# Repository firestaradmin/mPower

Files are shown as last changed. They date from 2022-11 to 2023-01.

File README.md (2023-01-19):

---
title: mPower [USB-C功率计、快充诱骗器]
tags: 
- Embedded
- ESP32
- product
categories:
- [PROJECT, product]
cover: /img/covers/mPowerV2.png
banner_img: /img/page/mPowerV2.png
index_img: /img/page/mPowerV2.png
sticky: 2
date: 2022-12-14
updated: 2023-1-18
---

# mPower [USB-C功率计、快充诱骗器]

---

@firestaradmin 2022-12-14

**本项目已开源至Github：[点我传送](https://github.com/firestaradmin/mPower)**

---

[TOC]

## 1、简介：

**为什么叫 mPower 呢？**
首先mPower 可以看作是一个迷你的power 相关的东西吧，其次也是我喜欢的一款车--BMW mPower 4 （😄）

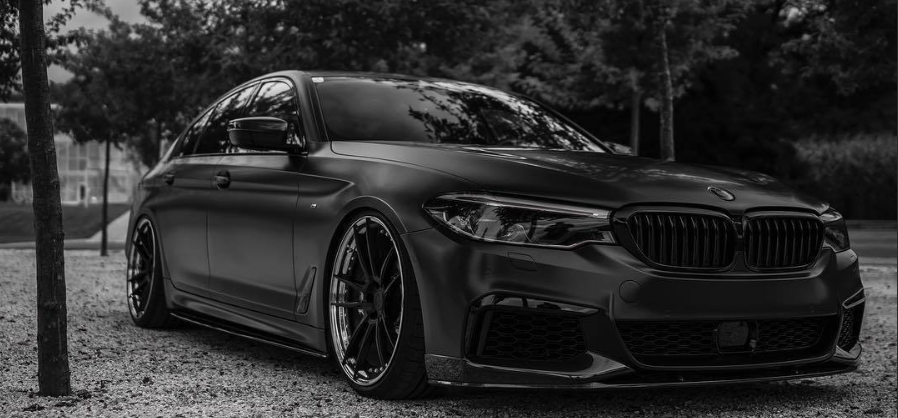
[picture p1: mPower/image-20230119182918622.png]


**功能介绍：**

首先是功率测量功能，顾名思义（USB-C功率计、快充诱骗器）它是一个USB-C 口的一个充电功率测量仪器，测量误差精确到`+-0.002 A/V`，但是DIY 作品并没有做偏差校准，所以并没有看上去那么精确，够用即可。

其次是PD快充协议诱骗功能，带有硬件开关一键诱骗，软件设置电压。如果快充适配器支持需要的电压就会输出该电压。

**硬件介绍：**

mPower 采用`ESP32-S2FH4`作为主控MCU，是一个单核 32 位 LX7 微处理器的 SoC，其内部集成4MB FLASH，支持WIFI 连接。

PCB 板载整合功能：USB串口电路、INA181电流检测芯片、一个SPI液晶屏幕IPX座子、一个输入端TYPE-C、一个输出TYPE-C、一个输出TYPE-A、一个输出正负极接线座子等

示意图：

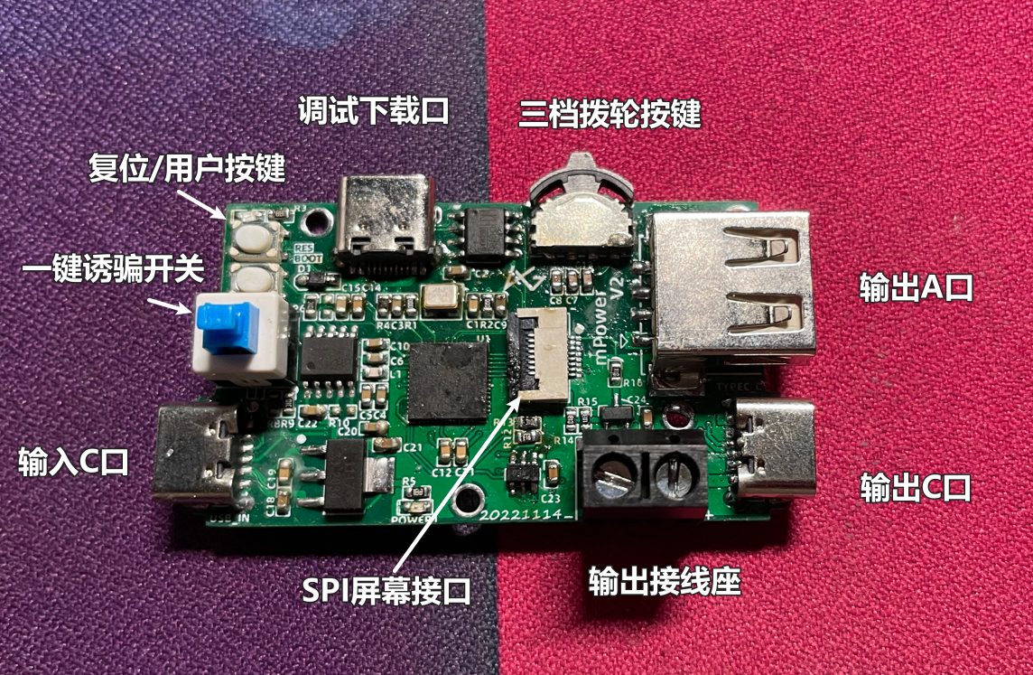
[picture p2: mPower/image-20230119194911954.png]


 背面靓照如下：

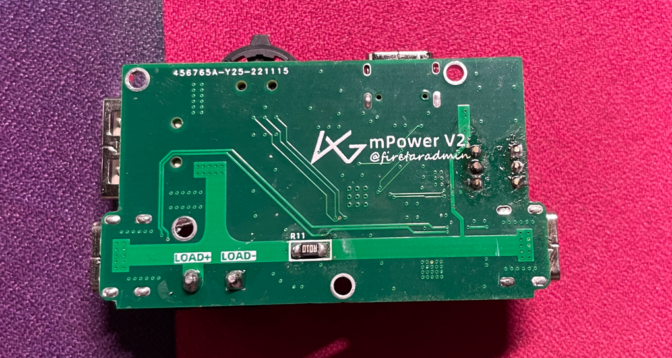
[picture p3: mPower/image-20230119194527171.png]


> mPower 本身是非常迷你的，尺寸只有 5CMx3CM

## 2、硬件电路部分

硬件电路部分，需要注意的是大电流走线宽度一定要够，其余的都很基础，参考器件的官方手册都可以解决，这里就不一一展示了，电路全部开源在GitHub。

诱骗采用的是 CH224K，支持PD协议的诱骗。

## 3、软件部分

软件部分，是基于FreeRTOS 的一个乐鑫提供SDK下开发的，整体思路就是ADC采集电压电流，然后计算转换为实际的电压电流显示在屏幕上。

电压采集直接ADC采集输出端或输入端的电压即可。

电流采集通过INA181芯片采集一个高精度的10毫欧采样电阻的电压来计算电流。

具体程序也开源在GitHub。

## 4、调试过程

因为我在制作这个东东的时候已经在准备辞职的事情了，所以上图二代的照片并没有记录其过程，这里只有一张第一代的mPower 的调试照片，还很糊，hhh。

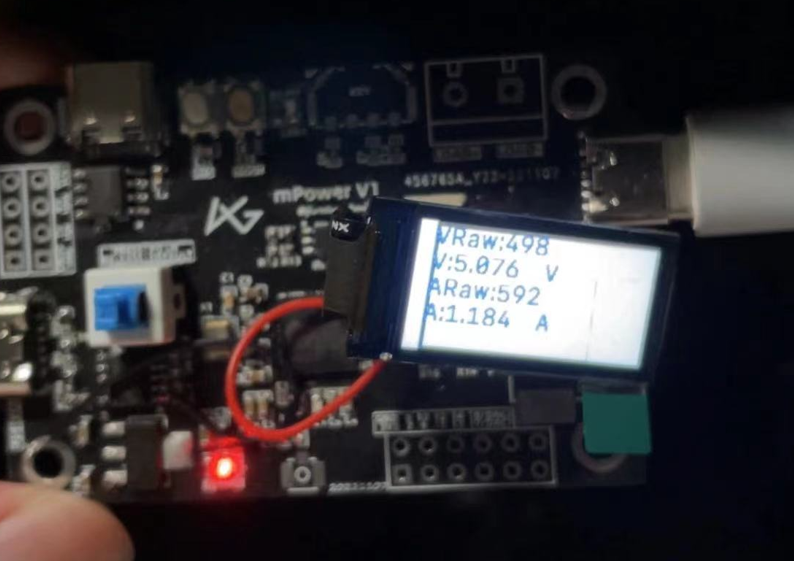
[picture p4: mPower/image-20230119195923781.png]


所以相应的，GUI界面也没有完善，但都是时间问题。

---

## X、作者的话

生活需要休息，迎接更好的挑战！

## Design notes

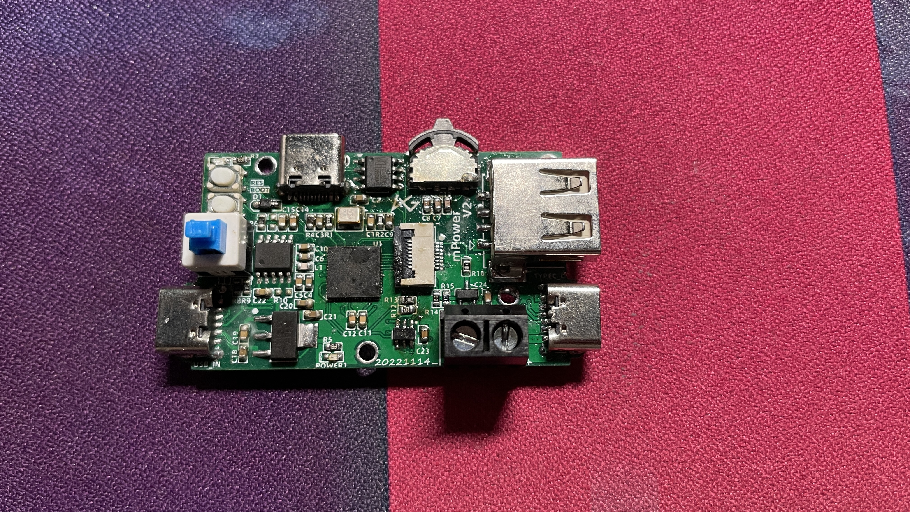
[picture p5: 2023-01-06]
doc/56c9ef24cccdd5a70391faf2373207a.jpg

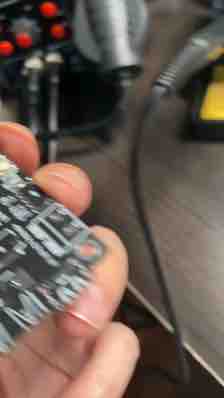
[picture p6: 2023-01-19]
doc/2e36afe427b3fbcd92cdb9f2c2f3921a.jpg

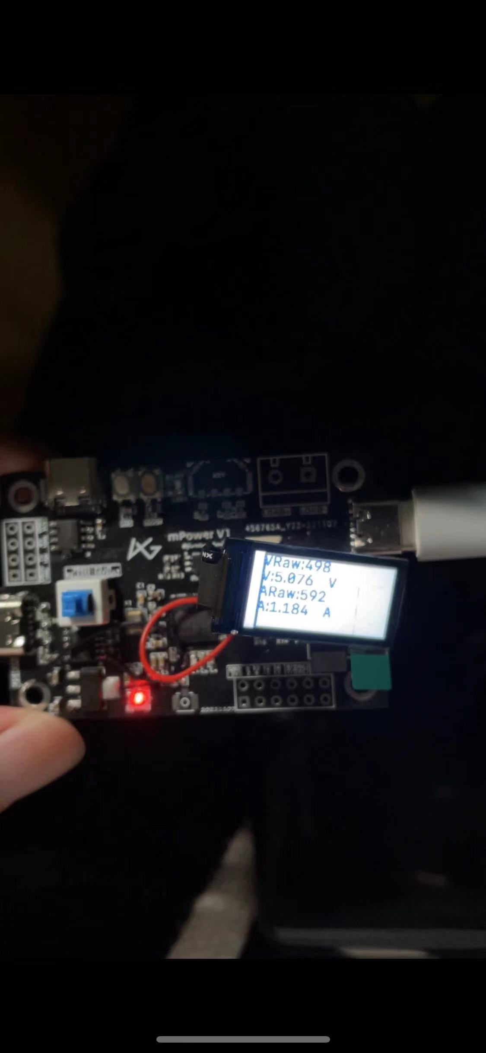
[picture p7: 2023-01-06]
doc/536347d712ec5ec59fe040279a1ce6b.jpg

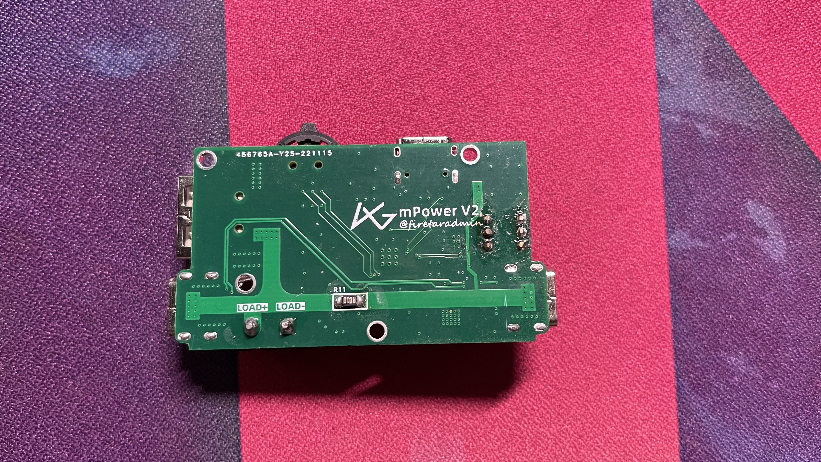
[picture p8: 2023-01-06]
doc/bbff5ff1d512dab57e9978423b1fdb3.jpg

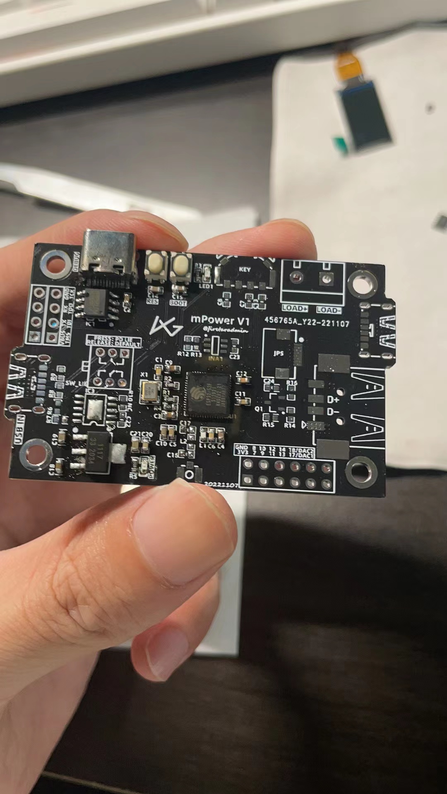
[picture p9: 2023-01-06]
doc/4cfd1c19e20c079220a8268f7ee3ccd.jpg

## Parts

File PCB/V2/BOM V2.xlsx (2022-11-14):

Comment | Description | Designator | Footprint | LibRef | Quantity
IPEX | IPEX 天线座子 | ANT1 | IPEX-3Pin | IPEX | 1
10nF | 无极性贴片电容 | C1 | C 0603_L | C | 1
0.1uF | 无极性贴片电容 | C2, C5, C6, C7, C8, C10, C11, C13, C14, C15, C19, C20, C23, C24 | C 0603_L | C | 14
1uF | 无极性贴片电容 | C3, C4, C9, C22 | C 0603_L | C | 4
100pF | 无极性贴片电容 | C12 | C 0603_L | C | 1
3.5pF | 无极性贴片电容 | C16 | C 0603_L | C | 1
3pF | 无极性贴片电容 | C17 | C 0603_L | C | 1
10uF | 无极性贴片电容 | C18, C21 | C 0603_L | C | 2
1N5819 SS14 | 肖特基二极管 | D1 | SOD-323 | 1N5819 | 1
CH340N | USB 转串口芯片 CH330/CH340N | IC1 | SOP8_N | CH340N | 1
SSP1117-3.3 | LDO 3.3V 1A 压差1.3V （x~20V 极限30V） | IC2 | SOT223_N | SSP1117-3.3 | 1
CH224K | 支持 4V 至 22V 输入电压 l 支持 PD3.0/2.0，BC1.2 等快充协议 l 支持 USB Type-C PD，支持正反插检测与自动切换 l 支持 E-Mark 模拟，自动检测 VCONN，支持 100W 功率 | IC3 | ESSOP10-1mm | CH224K | 1
INA181A1 | 电流检测 | INA1 | SOT23-6L | INA181A1 | 1
FPC0.5-8P | FPC连接器 | JP5 | FPC0.5 2H-WS-8P | FPC-8P | 1
EX-IO | 6*2P接插件 | JP_EX-IO | HDR2.54-LI-2x6P | Header 6X2 | 1
JTAG | 4P接插件 | JP_JTAG | HDR2.54-LI-4P | Header 4 | 1
OUTPUT | 2P接插件 | JP_O | KF301-5.0-2P | Header 2 | 1
UART0 | 4P接插件 | JP_U | HDR2.54-LI-4P | Header 4 | 1
TM-2023 | 三角拨轮开关 | KEY | TM-2023 | TM-2023 | 1
Boot | TS-3x4x2.5mm-4pin 轻触按键 | KEY_BOOT | TSMD-3*4*2.5 | TS-3x4x2.5mm-4pin | 1
RES | TS-3x4x2.5mm-4pin 轻触按键 | KEY_RES | TSMD-3*4*2.5 | TS-3x4x2.5mm-4pin | 1
2nH | 小功率贴片电感 | L1, L2 | L 0603-L | L | 2
Blue | 贴片LED | LED1 | LED 0603B | LED-SMD | 1
RED | 贴片LED | POWER1 | LED 0603R | LED-SMD | 1
SS8550 | 高频放大-PNP型 | Q1 | SOT23-3N | 8550-SMD | 1
0R | 贴片电阻 | R1, R2 | R 0603_L | R | 2
1K | 贴片电阻 | R3, R5, R14 | R 0603_L | R | 3
10K | 贴片电阻 | R4, R7, R8, R9, R13, R15 | R 0603_L | R | 6
10K(NC) | 贴片电阻 | R6 | R 0603_L | R | 1
0R(NC) | 贴片电阻 | R10 | R 0603_L | R | 1
0.01R | 1206 合金采样电阻 1 W 贴片电阻 | R11 | R 1206_L | R | 1
91K(%1) | 贴片电阻 | R12 | R 0603_L | R | 1
10R | 贴片电阻 | R16 | R 0603_L | R | 1
KET 7X7 | 7*7自锁开关 | SW_LIE | KFT DIP-7X7 | KET 7X7 | 1
OUTPUT TYPEC |  | TYPEC_O | TYPE-C-6P | TYPE-C 6P | 1
ESP32-S2FH4 | 单核 32 位 LX7 微处理器的 SoC, 240Mhz , 4MB Flash | U1 | QFN-56_L7.0-W7.0-P0.40-TL-EP4.0 | ESP32-S2FH4 | 1
UART0 | Type-C 16Pin | USB_D | TYPE-C-16P | TypeC-16P | 1
INPUT TYPEC |  | USB_IN | TYPE-C-6P | TYPE-C 6P | 1
OUTPUT A | USB-A型母接口 | USB_O | USB-A/S_B | USB-A/S | 1
40M | 4脚有源晶振 | X1 | OSC 3225-4P | XTAL-ACT-4P | 1

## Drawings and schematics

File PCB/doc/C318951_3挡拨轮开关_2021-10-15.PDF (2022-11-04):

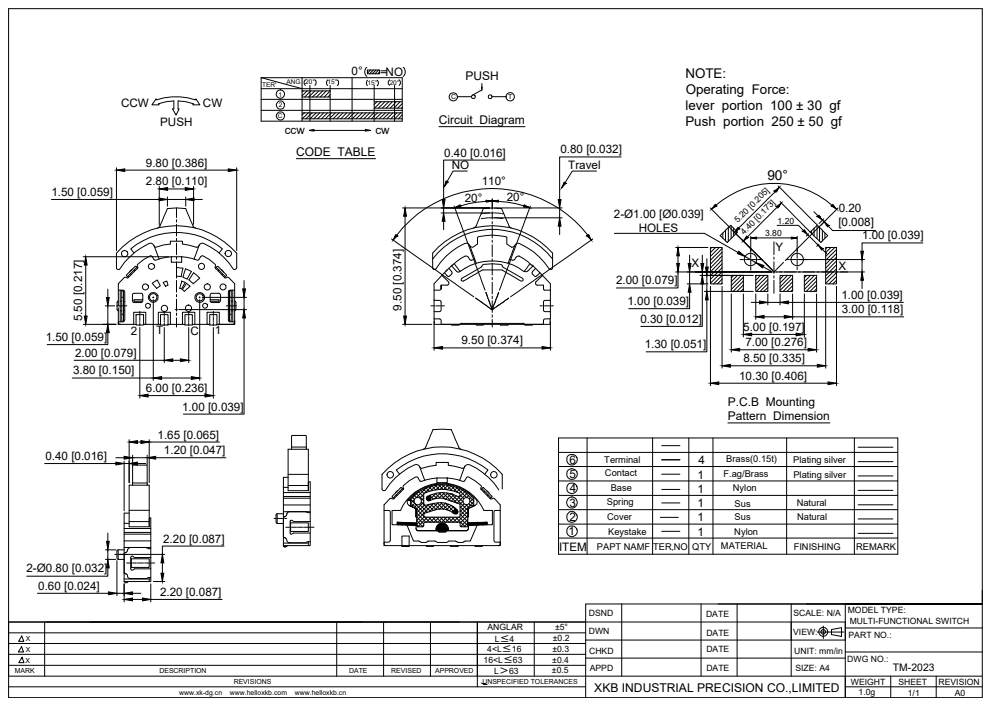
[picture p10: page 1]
XKB INDUSTRIAL PRECISION CO.,LIMITED; MODEL TYPE: PART NO.: DWG NO.: WEIGHT; SHEET; REVISION VIEW: SCALE: N/A UNIT: mm/in SIZE: A4; A0 DSND; DATE DWN CHKD APPD; DATE DATE DATE L≤4; ±0.5 ANGLAR; ±0.3 ±0.4 ±5° ±0.2 DATE; REVISED; APPROVED; 4<L≤16 16<L≤63 L>63 UNSPECIFIED TOLERANCES MARK; DESCRIPTION; REVISIONS XXX; www.xk-dg.cn www.helloxkb.com www.helloxkb.cn; MULTI-FUNCTIONAL SWITCH TM-2023 Contact Terminal Spring Base Cover Keystake ITEM PAPT NAMF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

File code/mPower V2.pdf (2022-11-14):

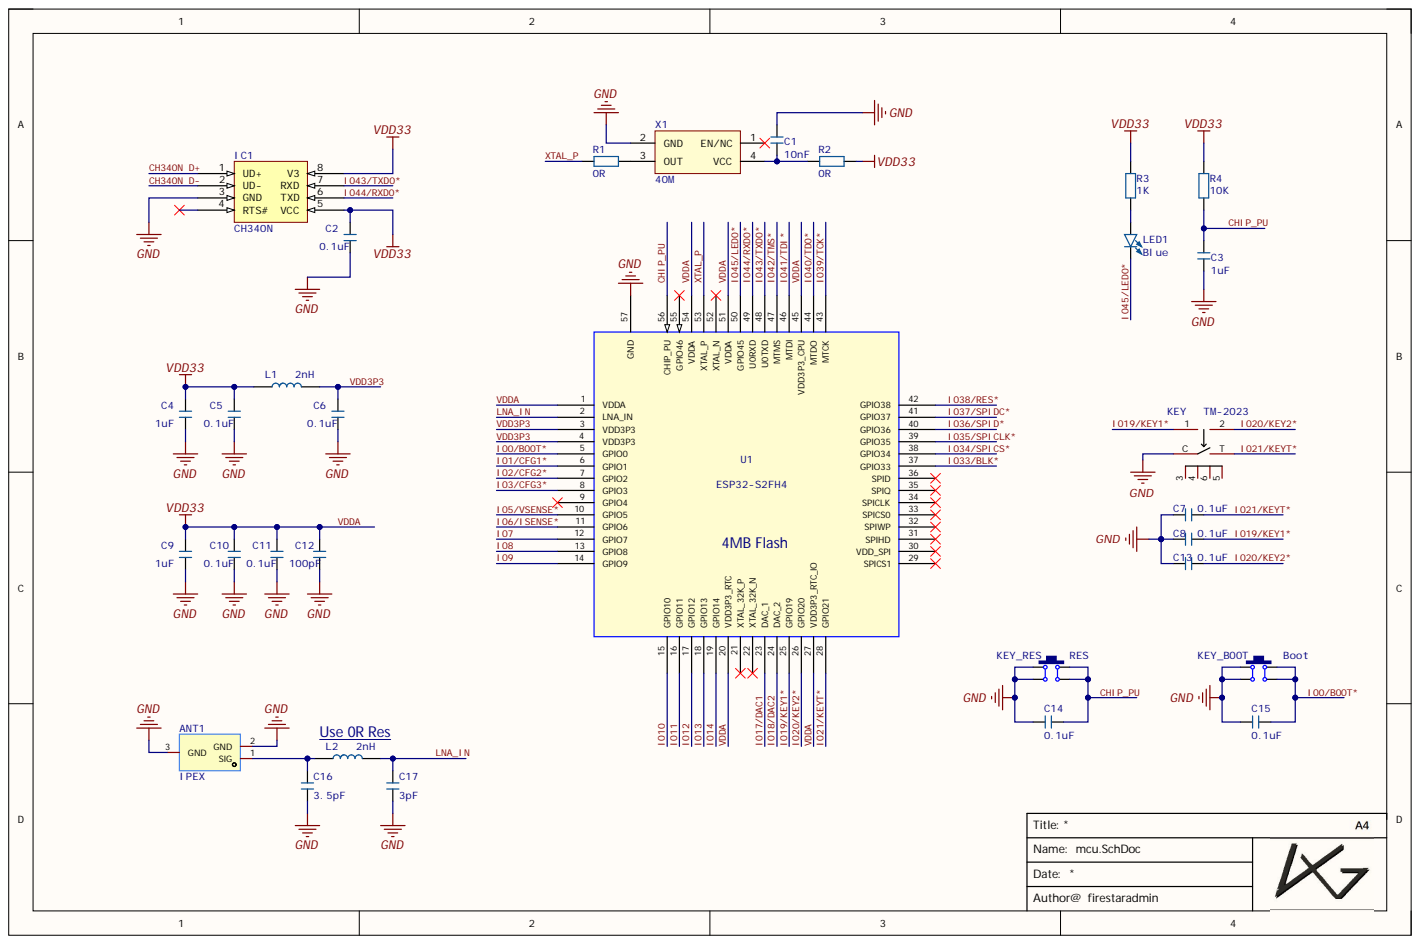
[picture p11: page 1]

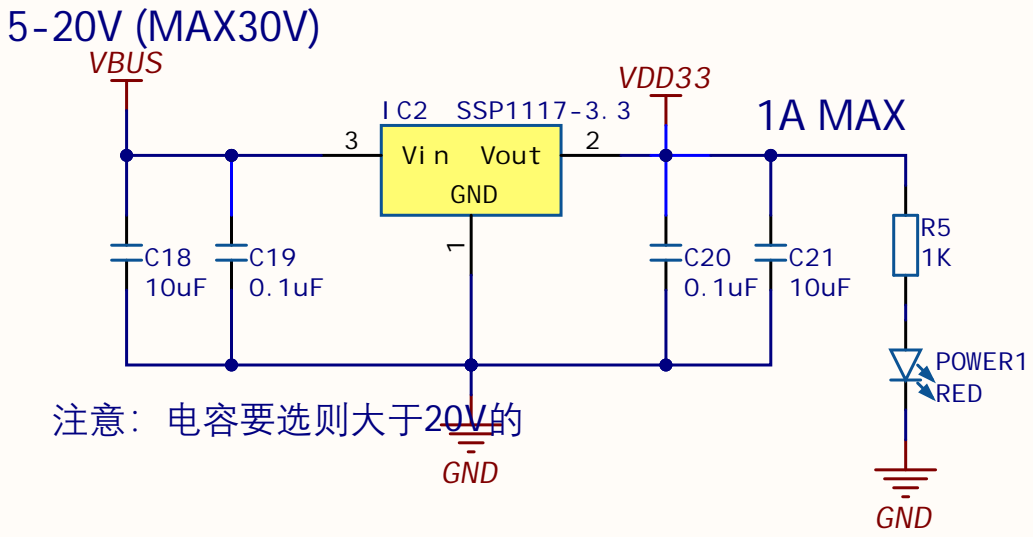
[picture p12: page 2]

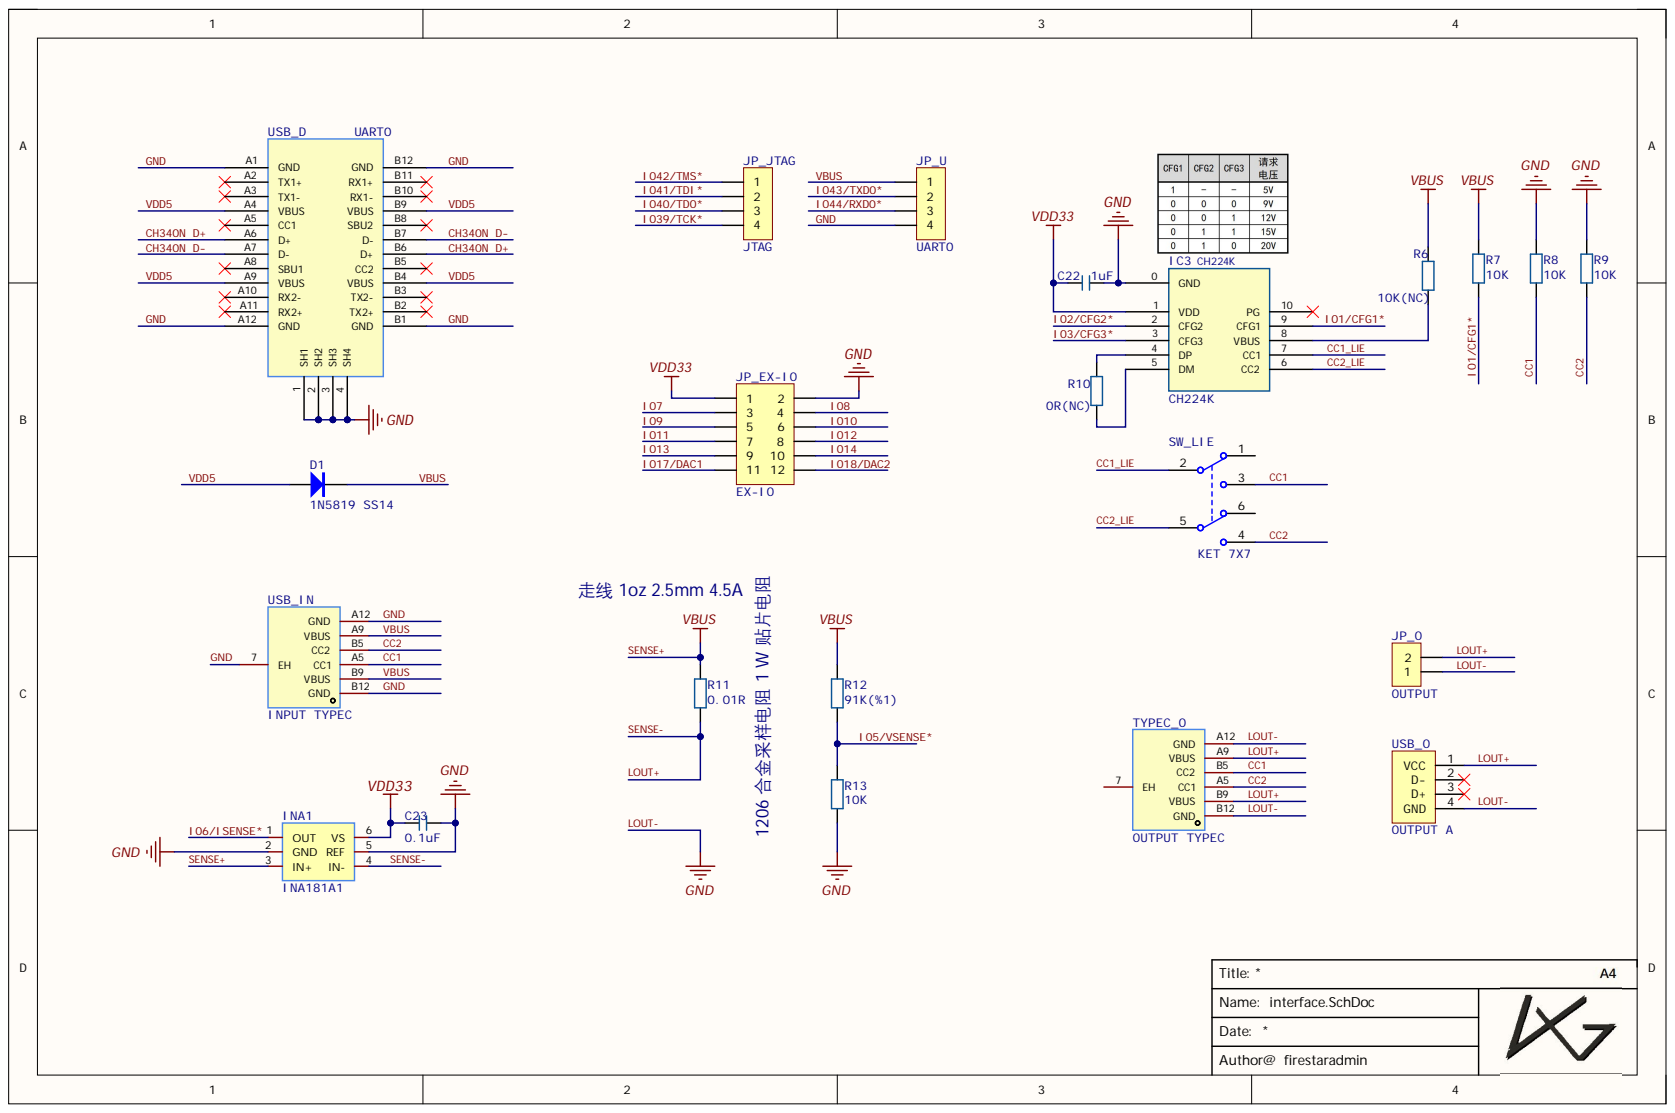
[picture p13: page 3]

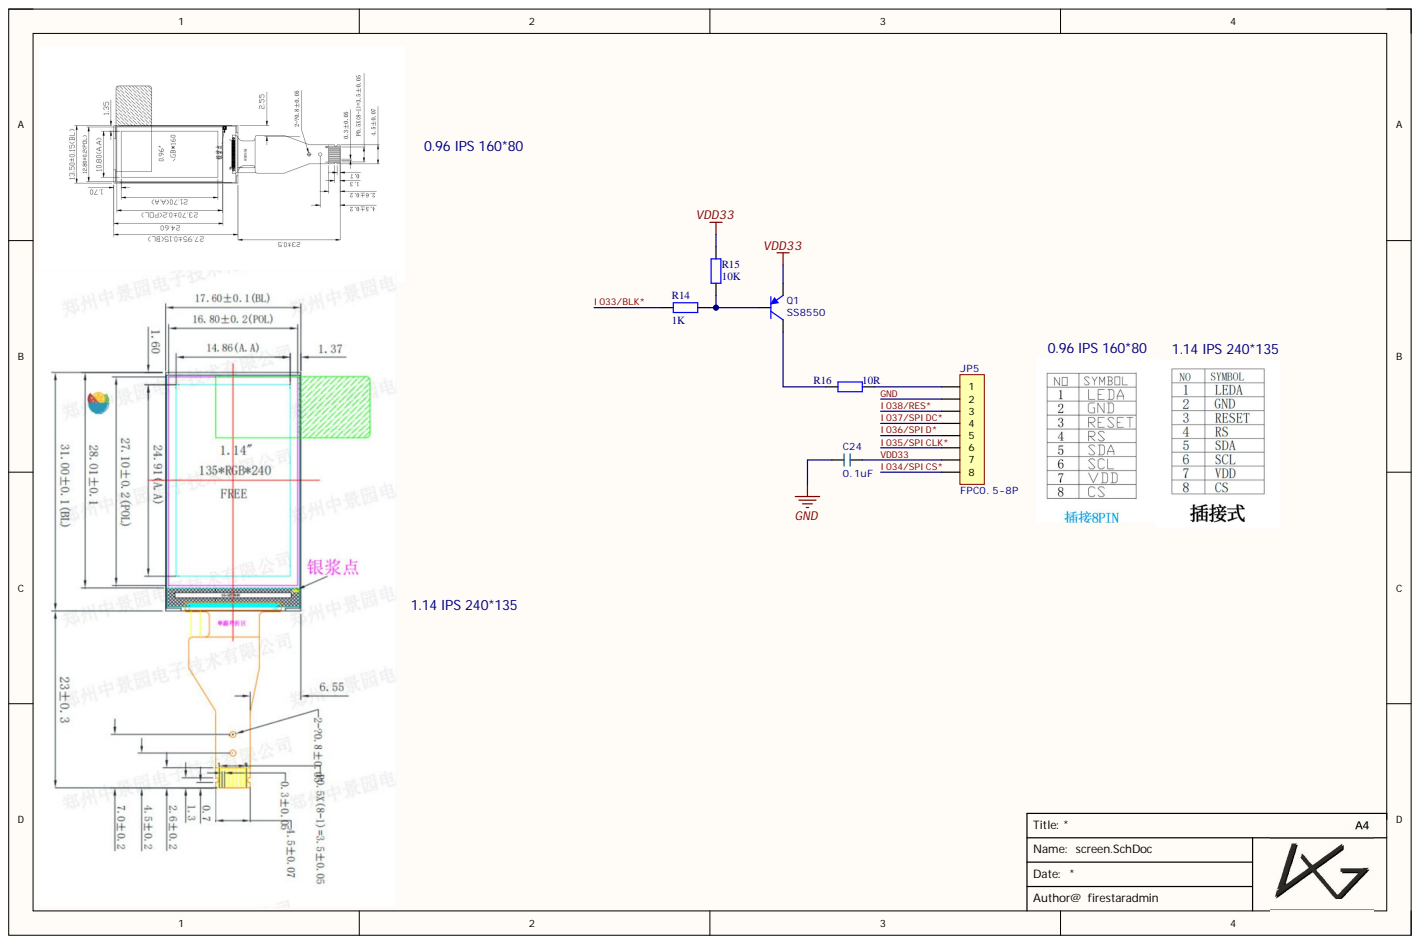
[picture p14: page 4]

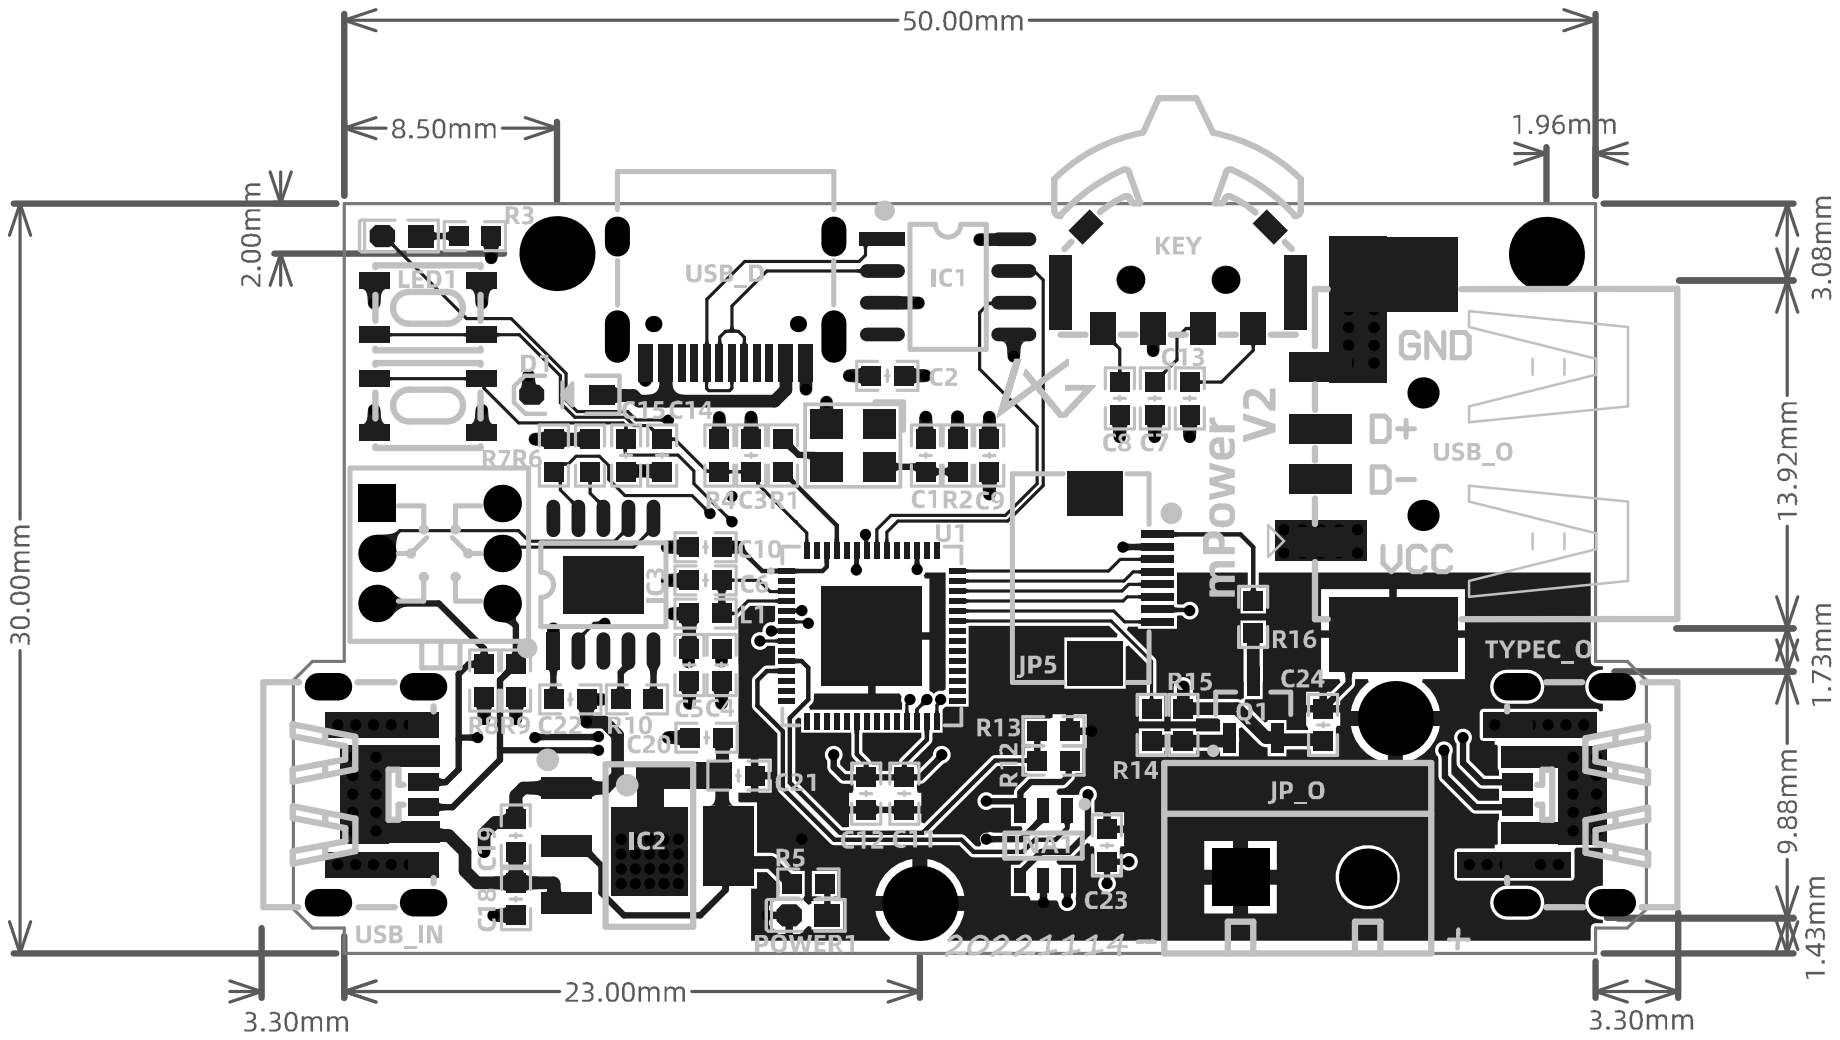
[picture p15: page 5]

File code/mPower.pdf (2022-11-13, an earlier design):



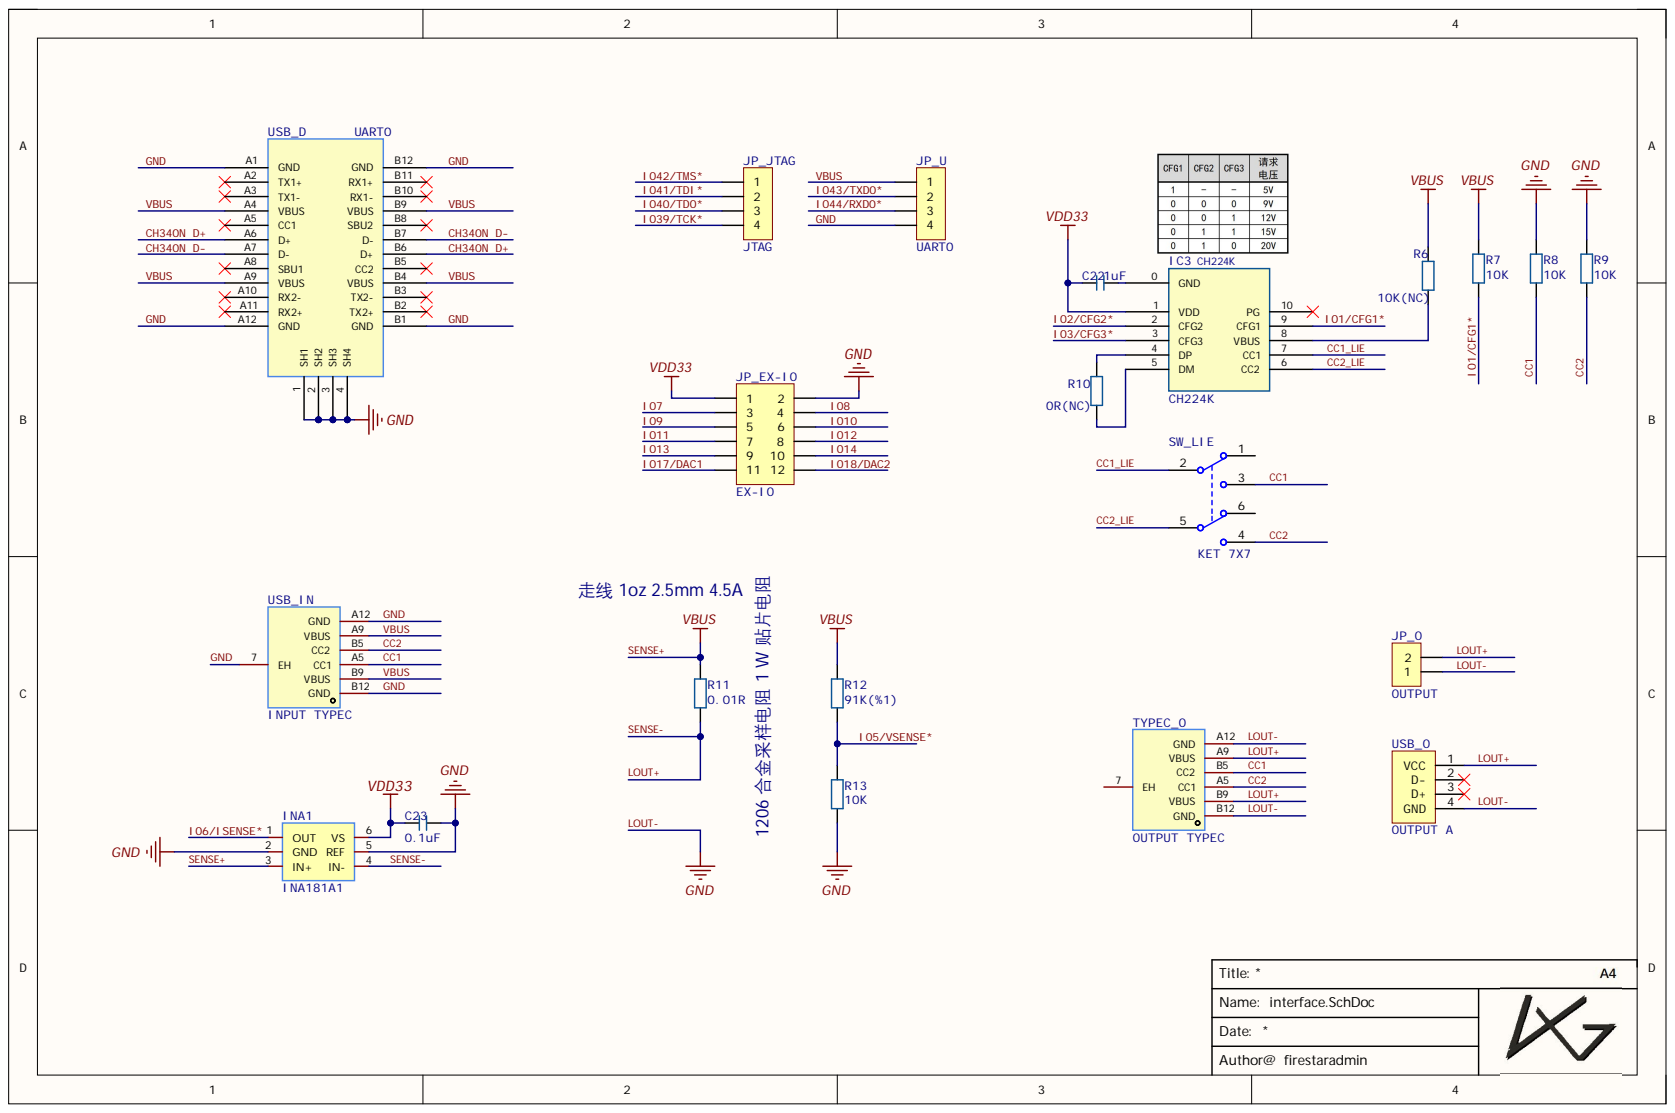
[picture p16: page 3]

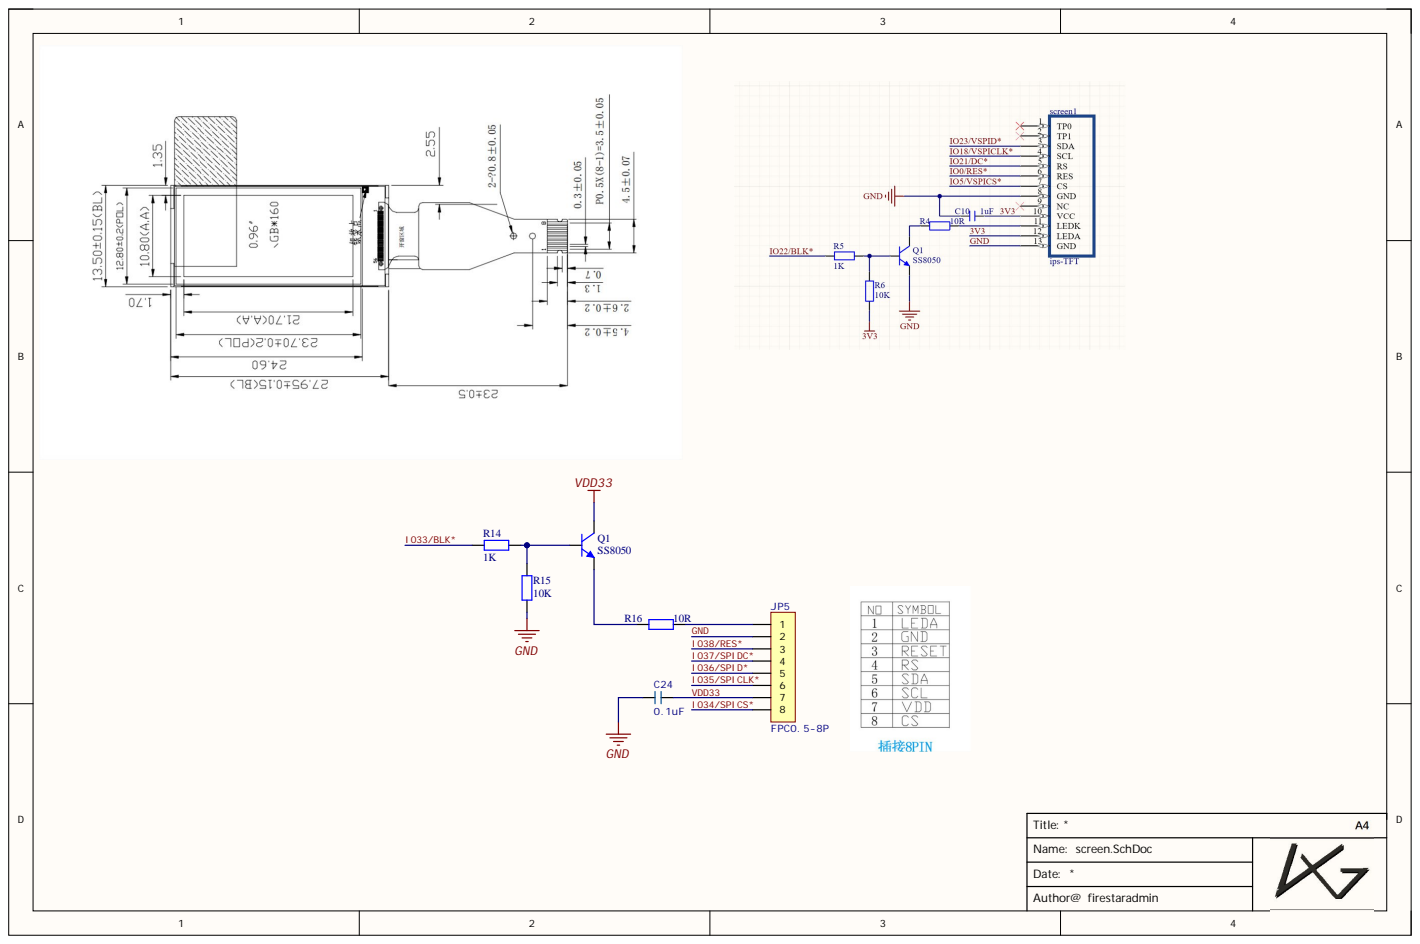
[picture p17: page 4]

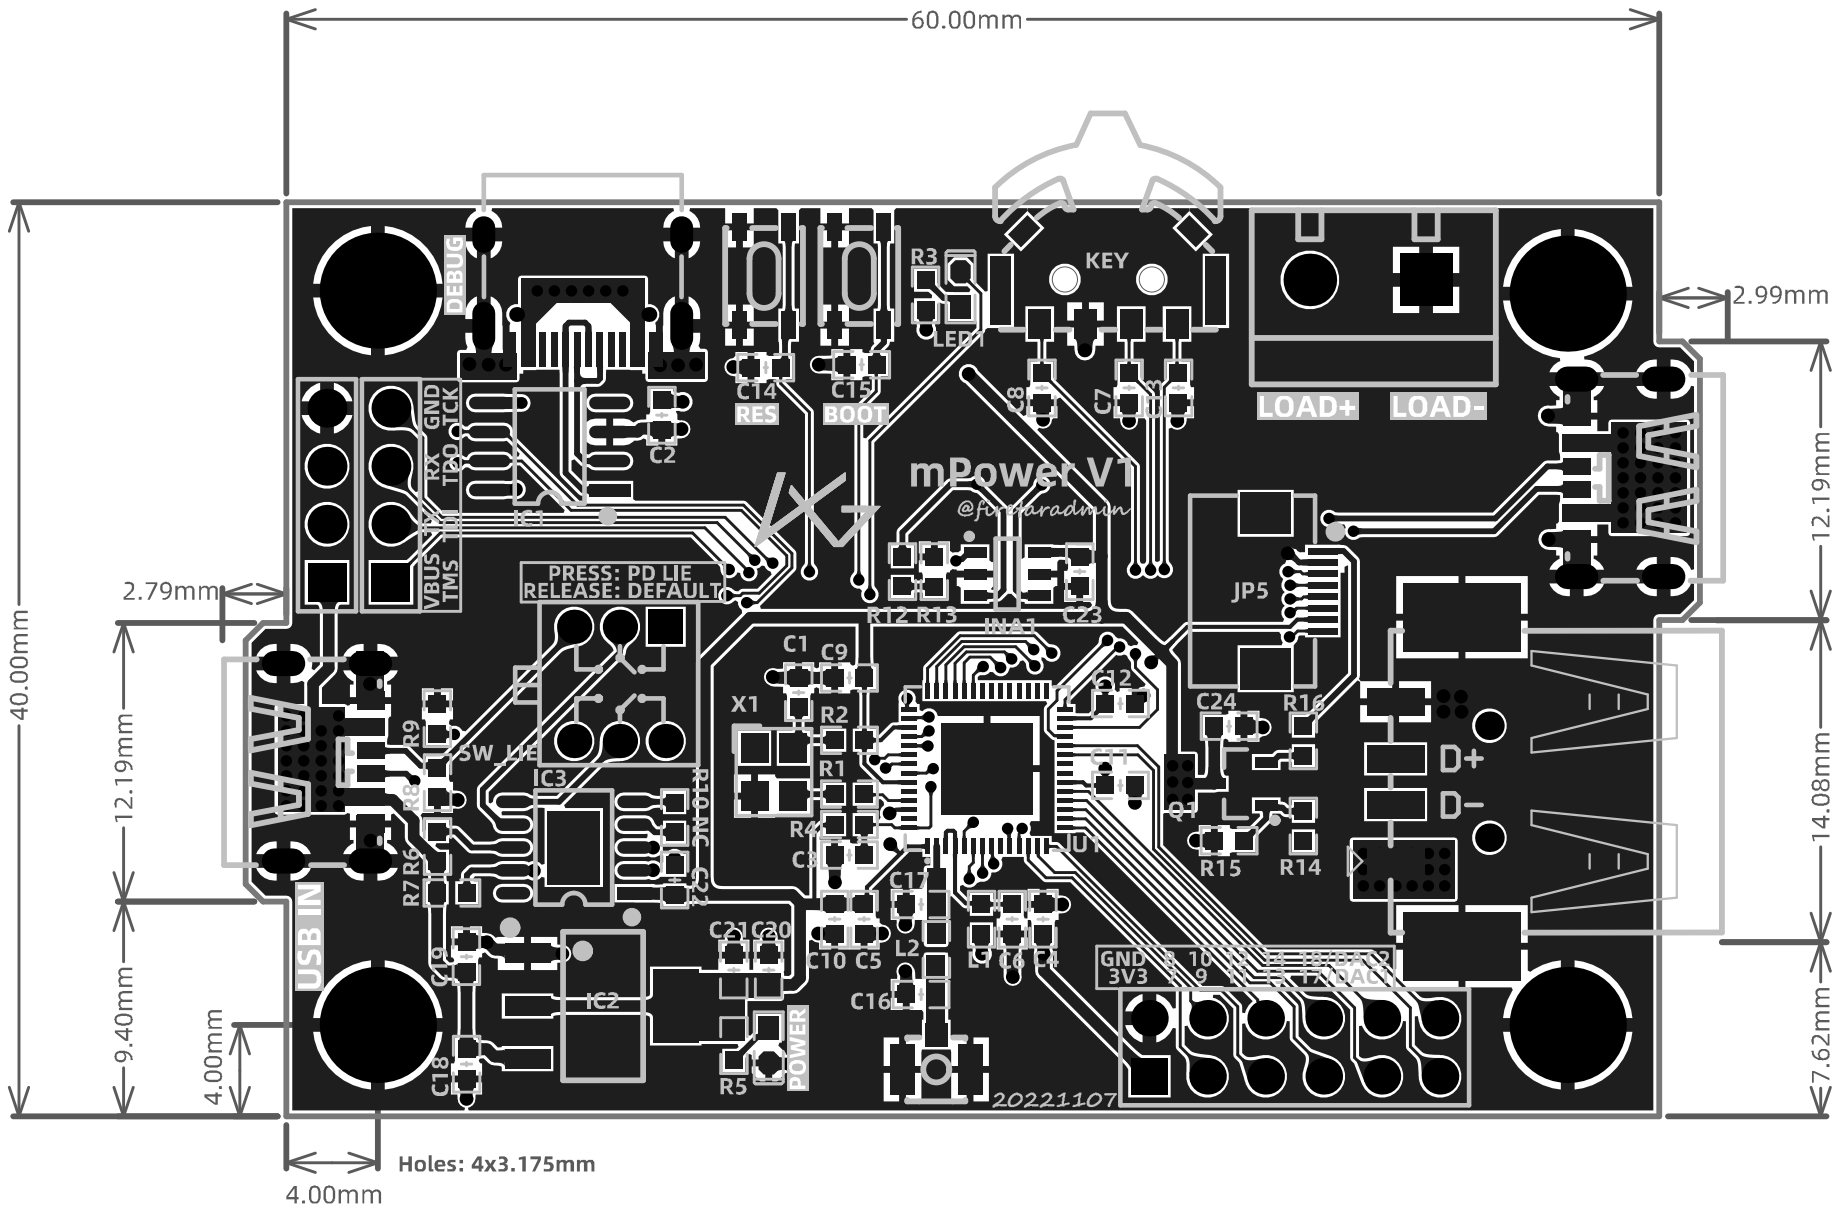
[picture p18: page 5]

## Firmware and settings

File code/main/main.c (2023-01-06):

/* 
 * Kite_V1 core board demo
 */
#include <stdio.h>
#include "sdkconfig.h"
#include "freertos/FreeRTOS.h"
#include "freertos/task.h"
#include "freertos/semphr.h"
#include "esp_system.h"
#include "driver/gpio.h"
#include "driver/adc.h"
#include "esp_adc_cal.h"


#include "key.h"
#include "led.h"
#include "lcd_st7789.h"

#include "ug_log.h"

/* LVGL */
#include "ug_log.h"
#include "lvgl.h"
#include "lv_port_disp.h"


void vOtherFunction( void );
void vTask_ug_tick( void * pvParameters );
void vTask_adc_task(void *pvParameters);


SemaphoreHandle_t xSemaphore = NULL;
static char buf[200];



// adc
static esp_adc_cal_characteristics_t *adc_chars;
static const adc_channel_t channelV = ADC_CHANNEL_4; 
static const adc_channel_t channelA = ADC_CHANNEL_5; 
static const adc_bits_width_t width = ADC_WIDTH_BIT_13;
static const adc_unit_t unit = ADC_UNIT_1;
static const adc_atten_t atten = ADC_ATTEN_DB_11;
#define DEFAULT_VREF    1100        //Use adc2_vref_to_gpio() to obtain a better estimate
#define NO_OF_SAMPLES   64          //Multisampling



void create_ui();
void vOtherFunction( void );
void gpio_init(void);
// void change_size_task(ug_task_t *p);
SemaphoreHandle_t ugLog_mutex;

void ugLogLock()
{
    xSemaphoreTake(ugLog_mutex, portMAX_DELAY );
    
}
void ugLogUnlock()
{
    xSemaphoreGive(ugLog_mutex);
}

void ug_log_mutex_init( )
{
    ugLog_mutex = xSemaphoreCreateMutex();
    if( ugLog_mutex == NULL )
    {
        printf("ug log mutex err!\r\n");
    }
}

void app_main(void)
{
	printf("mPower demo!\n");
    ug_log_mutex_init();
    ug_log_init(ug_log_mutexWay_externel, printf, ugLogLock, ugLogUnlock);
    led_init();
	key_init();
    // lv_init();
    // lv_port_disp_init();

    // create_ui();

	vOtherFunction();
    UGINFO("every thing willl be ok!\r\n");

    lcd_init();
    lcd_fill(0, 0, 100, 100, 0xFFAA);
    while(1)
	{
        // lv_timer_handler();
	}




}




void gpio_init(void)
{
	gpio_config_t io_conf;
    //disable interrupt
    io_conf.intr_type = GPIO_PIN_INTR_DISABLE;
    //set as output mode
    io_conf.mode = GPIO_MODE_OUTPUT;
    //bit mask of the pins that you want to set,e.g.GPIO18/19
    io_conf.pin_bit_mask = ((1ULL<<6)) | ((1ULL<<2)) | ((1ULL<<1)) | ((1ULL<<3));
    //disable pull-down mode
    io_conf.pull_down_en = 0;
    //disable pull-up mode
    io_conf.pull_up_en = 0;
    //configure GPIO with the given settings
    gpio_config(&io_conf);

    gpio_set_level(1, 0);
    gpio_set_level(2, 1);
    gpio_set_level(3, 0);
    gpio_set_level(6, 1);




    // adc
    adc1_config_width(width);
    adc1_config_channel_atten(channelV, atten);
    adc1_config_channel_atten(channelA, atten);
    //Characterize ADC
    adc_chars = calloc(1, sizeof(esp_adc_cal_characteristics_t));
    esp_adc_cal_value_t val_type = esp_adc_cal_characterize(unit, atten, width, DEFAULT_VREF, adc_chars);
    // print_char_val_type(val_type);
}


void create_ui()
{
    lv_obj_t * btn = lv_btn_create(lv_scr_act());                   /*Add a button to the current screen*/
    lv_obj_set_pos(btn, 10, 10);                                    /*Set its position*/
    lv_obj_set_size(btn, 100, 50);                                  /*Set its size*/
    lv_obj_add_event_cb(btn, NULL, LV_EVENT_CLICKED, NULL); /*Assign a callback to the button*/

    lv_obj_t * label = lv_label_create(btn);                        /*Add a label to the button*/
    lv_label_set_text(label, "Button");                             /*Set the labels text*/
    lv_obj_center(label); 
}

// void change_size_task(ug_task_t *p)
// {
//     // static int adv = 2;
//     // ug_color_t color;
//     // if(text1->coords.x2 >= 159 || text1->coords.x1 <= 0){
//     //     adv *= -1;
//     //     color = ug_color_make(text1->coords.x1, text1->coords.x2, text1->coords.x2);
//     //     ug_label_set_color(text1, &color);
//     // }

// 	// ug_obj_move(text1,2,0);

//     static int a = 0;
//     // if(a == 0){
//     //     ug_label_set_text(text1, FA_GRIN_SQUINT"LXG");
//     //     a = 1;
//     // }
//     // else {
//     //     ug_label_set_text(text1, FA_GRIN_STARS"GGNB");
//     //     a = 0;
//     // }
//     if( xSemaphoreTake( xSemaphore, ( TickType_t ) 1000 ) == pdTRUE )
//     {

//         ug_label_set_text(text1, buf);

//         xSemaphoreGive( xSemaphore );
//     }
// }


// Function that creates a task.
void vOtherFunction( void )
{

    TaskHandle_t xHandle = NULL;
    TaskHandle_t xHandle2 = NULL;
    xSemaphore = xSemaphoreCreateBinary();

    if( xSemaphore != NULL )
    {
        xSemaphoreGive( xSemaphore );
        printf("success xSemaphoreGive( xSemaphore );\r\n");
        // The semaphore was created successfully.
        // The semaphore can now be used.
    }
 // Create the task, storing the handle.  Note that the passed parameter ucParameterToPass
 // must exist for the lifetime of the task, so in this case is declared static.  If it was just an
 // an automatic stack variable it might no longer exist, or at least have been corrupted, by the time
 // the new task attempts to access it.
	// xTaskCreate( vTask_ug_tick, "vTask_ug_tick", 1024, NULL, 9, &xHandle );
	// configASSERT( xHandle );
	// xTaskCreate( vTask_adc_task, "vTask_adc_task", 4096, NULL, 8, &xHandle2 );
	// configASSERT( xHandle2 );

	// Use the handle to delete the task.
	// if( xHandle != NULL )
	// {
	// 	vTaskDelete( xHandle );
	// }
}



// Task to be created.
void vTask_ug_tick( void * pvParameters )
{
	for( ;; )
	{
		// Task code goes here.
		lv_tick_inc(10);
		vTaskDelay(10 / portTICK_PERIOD_MS);
    }
}


// Task to be created.
void vTask_adc_task( void * pvParameters )
{
    //Continuously sample ADC1
    uint32_t adc_reading = 0;
    uint32_t adc_readingA = 0;
    uint32_t voltage = 0;
    float act_voltage = 0;
    float act_voltage_f = 0;
    uint32_t voltageA = 0;
    float act_voltageA = 0;
    float act_voltageA_f = 0;
    float act_watt = 0;
    uint32_t R1 = 9900;
    uint32_t R2 = 91000;
    int i = 0;
    while (1) {
        adc_reading = 0;
        voltage = 0;
        //Multisampling
        for (i = 0; i < NO_OF_SAMPLES; i++) {
            if (unit == ADC_UNIT_1) {
                adc_reading += adc1_get_raw((adc1_channel_t)channelV);
                adc_readingA += adc1_get_raw((adc1_channel_t)channelA);
            }
        }
        adc_reading /= NO_OF_SAMPLES;
        adc_readingA /= NO_OF_SAMPLES;
        //Convert adc_reading to voltage in mV
        voltage = esp_adc_cal_raw_to_voltage(adc_reading, adc_chars);
        voltageA = esp_adc_cal_raw_to_voltage(adc_readingA, adc_chars);
        if(voltage>=12)
            voltage -= 12;
        else
            voltage = 0;
        if(voltageA>=36)
            voltageA -= 36;
        else
            voltageA = 0;
        act_voltage = (float)(voltage) * (float)(R1 + R2) / (float)R1;
        act_voltage_f = act_voltage/1000;
        act_voltageA = (float)voltageA/0.01/50;
        act_voltageA_f = act_voltageA/1000;
        act_watt = act_voltage_f * act_voltageA_f;
        // printf("Raw: %d\tVoltage: %dmV\n", adc_reading, act_voltage);
        if( xSemaphoreTake( xSemaphore, ( TickType_t ) 1000 ) == pdTRUE )
        {
            memset(buf, 0, 200);
            snprintf(buf, 200, "%.2fV%.2fA\n%.3fW",act_voltage_f,act_voltageA_f,act_watt);

            xSemaphoreGive( xSemaphore );
        }




        vTaskDelay(pdMS_TO_TICKS(500));
    }
}

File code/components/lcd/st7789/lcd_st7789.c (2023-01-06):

#include <stdio.h>
#include <stdlib.h>
#include <string.h>
#include "freertos/FreeRTOS.h"
#include "freertos/task.h"
#include "esp_system.h"
#include "driver/spi_master.h"
#include "driver/gpio.h"
#include "lcd_st7789.h"

static void lcd_spi_pre_transfer_callback(spi_transaction_t *t);

#define LCD_WR_REG lcd_wr_reg
#define LCD_WR_DATA lcd_wr_data_16bit
#ifdef USE_INT_RAM
DRAM_ATTR uint16_t lcd_ram[RES_HOR][RES_VER];
#endif

#define LCD_HOST    HSPI_HOST
#define DMA_CHAN    2

#define PIN_NUM_MOSI 36
#define PIN_NUM_CLK  35
#define PIN_NUM_CS   34

#define PIN_NUM_DC   37
#define PIN_NUM_RST  38
#define PIN_NUM_BCKL 33

#define SPI_SPEED_MHz 26 * 1000 * 1000

esp_err_t ret;
static spi_device_handle_t spi;


// //Place data into DRAM. Constant data gets placed into DROM by default, which is not accessible by DMA.
// DRAM_ATTR static const lcd_init_cmd_t st_init_cmds[]={
//     /* Memory Data Access Control, MX=MV=1, MY=ML=MH=0, RGB=0 */
//     {0x36, {(1<<5)|(1<<6)}, 1},
//     /* Interface Pixel Format, 16bits/pixel for RGB/MCU interface */
//     {0x3A, {0x55}, 1},
//     /* Porch Setting */
//     {0xB2, {0x0c, 0x0c, 0x00, 0x33, 0x33}, 5},
//     /* Gate Control, Vgh=13.65V, Vgl=-10.43V */
//     {0xB7, {0x35}, 1},
//     /* VCOM Setting, VCOM=1.175V */
//     {0xBB, {0x19}, 1},
//     /* LCM Control, XOR: BGR, MX, MH */
//     {0xC0, {0x2c}, 1},
//     /* VDV and VRH Command Enable, enable=1 */
//     {0xC2, {0x01, 0xff}, 2},
//     /* VRH Set, Vap=4.4+... */
//     {0xC3, {0x12}, 1},
//     /* VDV Set, VDV=0 */
//     {0xC4, {0x20}, 1},
//     /* Frame Rate Control, 60Hz, inversion=0 */
//     {0xC6, {0x0f}, 1},
//     /* Power Control 1, AVDD=6.8V, AVCL=-4.8V, VDDS=2.3V */
//     {0xD0, {0xA4, 0xA1}, 1},
//     /* Positive Voltage Gamma Control */
//     {0xE0, {0xd0, 0x04, 0x0d, 0x11, 0x13, 0x2b, 0x3f, 0x54, 0x4c, 0x18, 0x0d, 0x0b, 0x1f, 0x23}, 14},
//     /* Negative Voltage Gamma Control */
//     {0xE1, {0xd0, 0x04, 0x0c, 0x11, 0x13, 0x2c, 0x3f, 0x44, 0x51, 0x2f, 0x1f, 0x1f, 0x20, 0x23}, 14},
//     // /* Positive Voltage Gamma Control */
//     // {0xE0, {0xD0, 0x00, 0x05, 0x0E, 0x15, 0x0D, 0x37, 0x43, 0x47, 0x09, 0x15, 0x12, 0x16, 0x19}, 14},
//     // /* Negative Voltage Gamma Control */
//     // {0xE1, {0xD0, 0x00, 0x05, 0x0D, 0x0C, 0x06, 0x2D, 0x44, 0x40, 0x0E, 0x1C, 0x18, 0x16, 0x19}, 14},
//     /* Sleep Out */
//     {0x11, {0}, 0x80},
//     /* Display On */
//     {0x29, {0}, 0x80},
//     {0, {0}, 0xff}

// };





//This function is called (in irq context!) just before a transmission starts. It will
//set the D/C line to the value indicated in the user field.
void lcd_spi_pre_transfer_callback(spi_transaction_t *t)
{
    int dc=(int)t->user;
    gpio_set_level(PIN_NUM_DC, dc);
}



/* Send a command to the LCD. Uses spi_device_polling_transmit, which waits
 * until the transfer is complete.
 *
 * Since command transactions are usually small, they are handled in polling
 * mode for higher speed. The overhead of interrupt transactions is more than
 * just waiting for the transaction to complete.
 */
void lcd_cmd(spi_device_handle_t spi, const uint8_t cmd)
{
    esp_err_t ret;
    spi_transaction_t t;
    memset(&t, 0, sizeof(t));       //Zero out the transaction
    t.length=8;                     //Command is 8 bits
    t.tx_buffer=&cmd;               //The data is the cmd itself
    t.user=(void*)0;                //D/C needs to be set to 0
    ret=spi_device_polling_transmit(spi, &t);  //Transmit!
    assert(ret==ESP_OK);            //Should have had no issues.
}
static void lcd_wr_reg(uint8_t cmd)
{
    esp_err_t ret;
    spi_transaction_t t;
    memset(&t, 0, sizeof(t));       //Zero out the transaction
    t.length=8;                     //Command is 8 bits
    t.tx_buffer=&cmd;               //The data is the cmd itself
    t.user=(void*)0;                //D/C needs to be set to 0
    ret=spi_device_polling_transmit(spi, &t);  //Transmit!
    assert(ret==ESP_OK);            //Should have had no issues.
}

/* Send data to the LCD. Uses spi_device_polling_transmit, which waits until the
 * transfer is complete.
 *
 * Since data transactions are usually small, they are handled in polling
 * mode for higher speed. The overhead of interrupt transactions is more than
 * just waiting for the transaction to complete.
 */
void lcd_data(spi_device_handle_t spi, const uint8_t *data, int len)
{
    esp_err_t ret;
    spi_transaction_t t;
    if (len==0) return;             //no need to send anything
    memset(&t, 0, sizeof(t));       //Zero out the transaction
    t.length=len*8;                 //Len is in bytes, transaction length is in bits.
    t.tx_buffer=data;               //Data
    t.user=(void*)1;                //D/C needs to be set to 1
    ret=spi_device_polling_transmit(spi, &t);  //Transmit!
    assert(ret==ESP_OK);            //Should have had no issues.
}

void lcd_wr_data_8bit(uint8_t data)
{
    esp_err_t ret;
    spi_transaction_t t;
    uint8_t txdata[1];
    txdata[0] = (uint8_t)data;
    memset(&t, 0, sizeof(t));       //Zero out the transaction
    t.length=8;                 //Len is in bytes, transaction length is in bits.
    t.tx_buffer=txdata;               //Data
    t.user=(void*)1;                //D/C needs to be set to 1
    ret=spi_device_polling_transmit(spi, &t);  //Transmit!
    assert(ret==ESP_OK);            //Should have had no issues.
}


void lcd_wr_data_16bit(uint16_t data)
{
    esp_err_t ret;
    spi_transaction_t t;
    uint8_t txdata[2];
    txdata[0] = data >> 8;
    txdata[1] = (uint8_t)data;
    memset(&t, 0, sizeof(t));       //Zero out the transaction
    t.length=2*8;                 //Len is in bytes, transaction length is in bits.
    t.tx_buffer=txdata;               //Data
    t.user=(void*)1;                //D/C needs to be set to 1
    ret=spi_device_polling_transmit(spi, &t);  //Transmit!
    assert(ret==ESP_OK);            //Should have had no issues.
}

// lcd_cmd(spi, st_init_cmds[cmd].cmd);
// lcd_data(spi, st_init_cmds[cmd].data, st_init_cmds[cmd].databytes&0x1F);
#define LCD_WR_REG(x) lcd_wr_reg(x)
#define LCD_WR_DATA8(x) lcd_wr_data_8bit(x)
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

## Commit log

2022-10-30 Mon Oct 31 01:12:03 2022 with push.sh
    [mPower.PrjPcb, main.SchDoc]
2022-11-02 Thu Nov 3 00:39:24 2022 with push.sh V1.3
    [V1.PcbDoc, interface.SchDoc, mPower.PrjPcb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]
2022-11-02 Thu Nov 3 01:13:19 2022 with push.sh V1.3
    [interface.SchDoc, mcu.SchDoc, power.SchDoc]
2022-11-03 20% | with push.sh V1.3
    [interface.SchDoc, mPower.PrjPcb, mcu.SchDoc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]
2022-11-04 add some doc, 51% | with push.sh V1.3
    [interface.SchDoc, mcu.SchDoc, power.SchDoc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]
2022-11-05 60% | with push.sh V1.3
    [interface.SchDoc, mcu.SchDoc, power.SchDoc]
2022-11-05 start pcb | with push.sh V1.3
    [interface.SchDoc, mPower.PrjPcb, mcu.SchDoc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]
2022-11-06 Sun Nov 6 19:26:30 2022 with push.sh V1.3
    [interface.SchDoc]
2022-11-06 Sun Nov 6 23:17:49 2022 with push.sh V1.3
    [interface.SchDoc]
2022-11-07 pcb over, add gerber | with push.sh V1.3
    [V1.GBL, V1.GBO, V1.GBP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]
2022-11-07 add bom | with push.sh V1.3
    [BOM V1.xlsx, mPower.PrjPcb]
2022-11-07 modified fpc name | with push.sh V1.3
    [BOM V1.xlsx, screen.SchDoc]
2022-11-13 add pdf, change font | with push.sh V1.3
    [interface.SchDoc, mPower.PrjPcb, mcu.SchDoc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]
2022-11-14 move pcb folder, add code folder | with push.sh V1.3
    [BOM V1.xlsx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]
2022-11-14 fix: fix pcb err() [Dch224k-GND, [2~ [3~) [Da [3~ [Da [2~ [) [D, Screen LED switch) | with push.sh V1.3
    [interface.SchDoc, mPower.PrjPcb, screen.SchDoc]
2022-11-14 V2 90% | with push.sh V1.3
    [interface.SchDoc, mPower.PrjPcb, screen.SchDoc]
2022-11-14 gen V2 file | with push.sh V1.3
    [BOM V1.xlsx, BOM V2.xlsx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]
2022-11-14 reGen V2 file | with push.sh V1.3
    [V2.GBL, V2.GBO, V2.GBP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]
2022-11-21 add st7789 driver | with push.sh V1.3
2023-01-06 添加图片视频
